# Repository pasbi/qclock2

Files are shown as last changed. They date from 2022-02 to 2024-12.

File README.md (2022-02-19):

# qclock2
Code, Schematics, Photos of the WortUhr Hack

The WORTUHR is a clock that displays the current time in form of glowing words.
This is about the German variant.

Note: The instance I got is presumably a cheap copy of a more expensive design https://qlocktwo.com/.

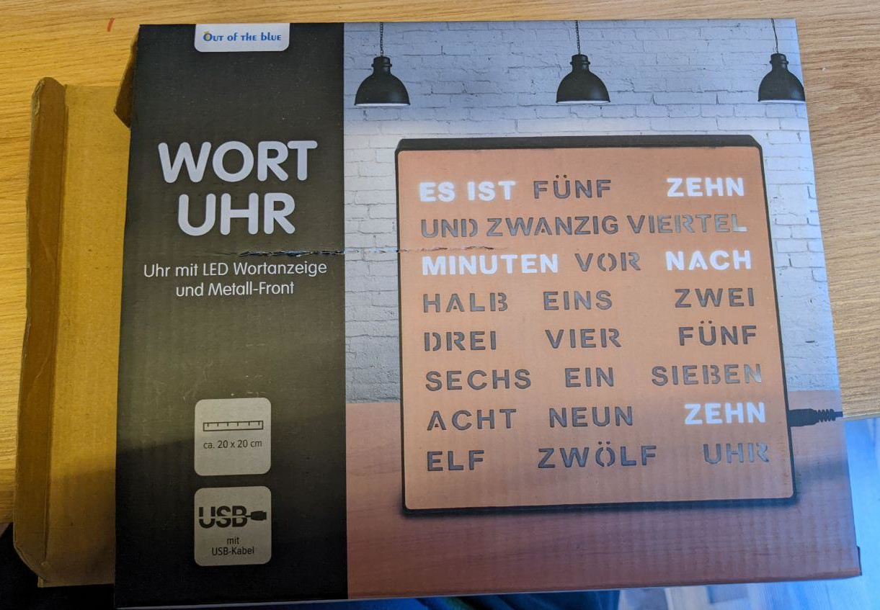
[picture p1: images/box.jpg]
Box


## Original Design

There is a metal cover of size 20cm x 20cm.
25 German words are blanked out.
It has a DC 5V 1A power connector and two buttons (`+`) and (`-`).
The plastic housing is 4 cm thick and encloses the metal sheet completey.
Inside there is a PCB whith 25 LED-groups, one group per word, with varying number of LEDs per group.
There's further two groups with each five LED drivers (transitor and multiple resistors), one IC, a quartz and few other passive components.
After powering the the PCB, the clock displays 12:00 ("ES IST ZWÖLF UHR").
The time can be adjusted using the two buttons.

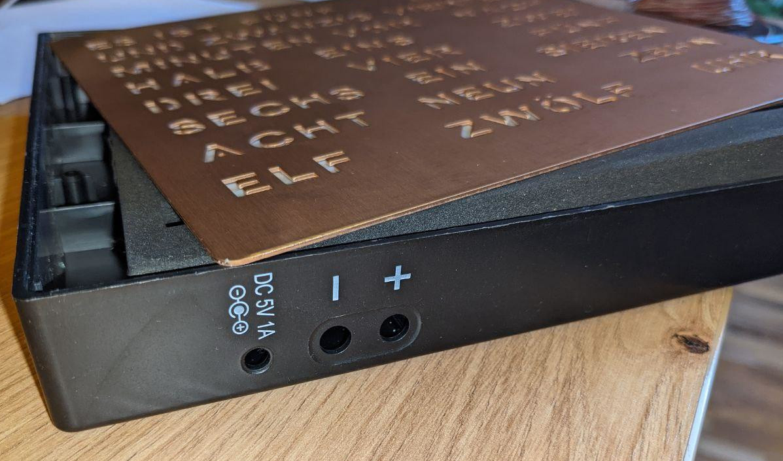
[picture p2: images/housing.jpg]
housing

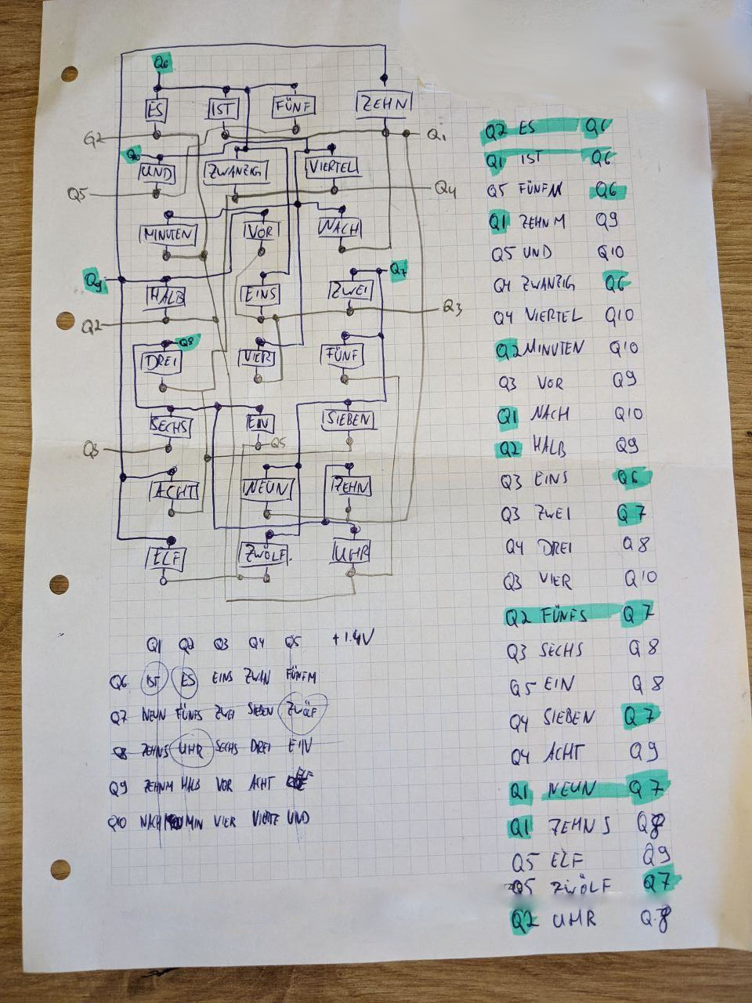
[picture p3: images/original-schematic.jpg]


## Problem

The problem with the original product is that it does reset every time power is disconnected.
That makes it inconvenient to use occasionally.

## Idea

Implement some circuit that synchronizes the time via NTP.

## Implementation

The original driver chip has been unsoldered, the 10 transistors on the board have been soldered to cables and dupont-connectors.

A 8266 and MCP23017 are connected via I²C.
The MCP keeps the time and synchronizes regularly via WIFI and NTP.
Since the watch works at 5V and the 8266 at 3.3V, a two-channel bidirectional logic level converter is required to translate the I²C signals.

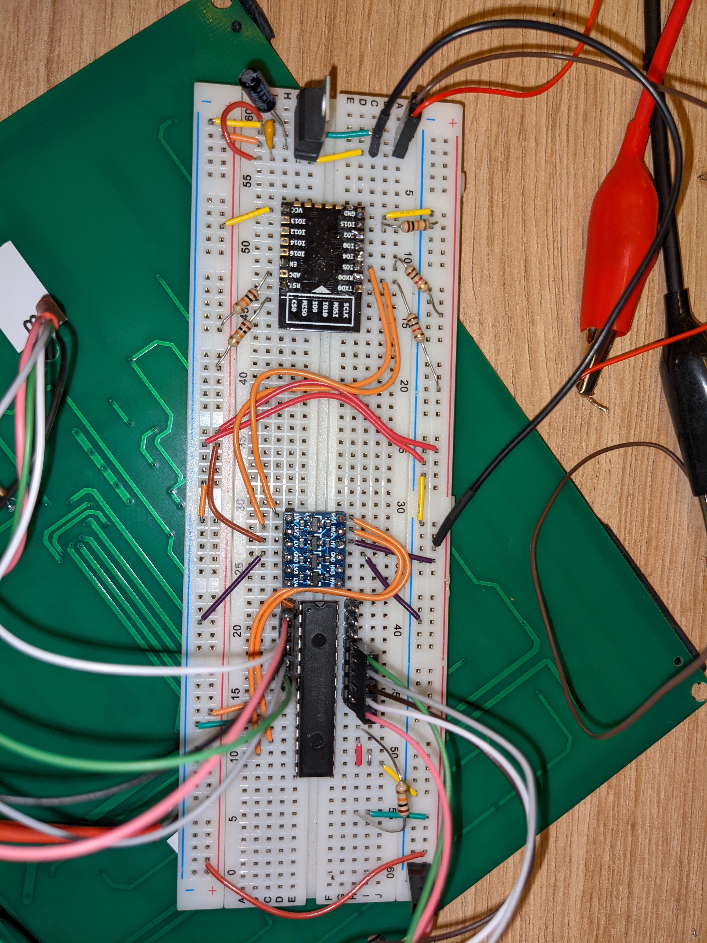
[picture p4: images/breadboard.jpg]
breadboard

breadboard-pcb
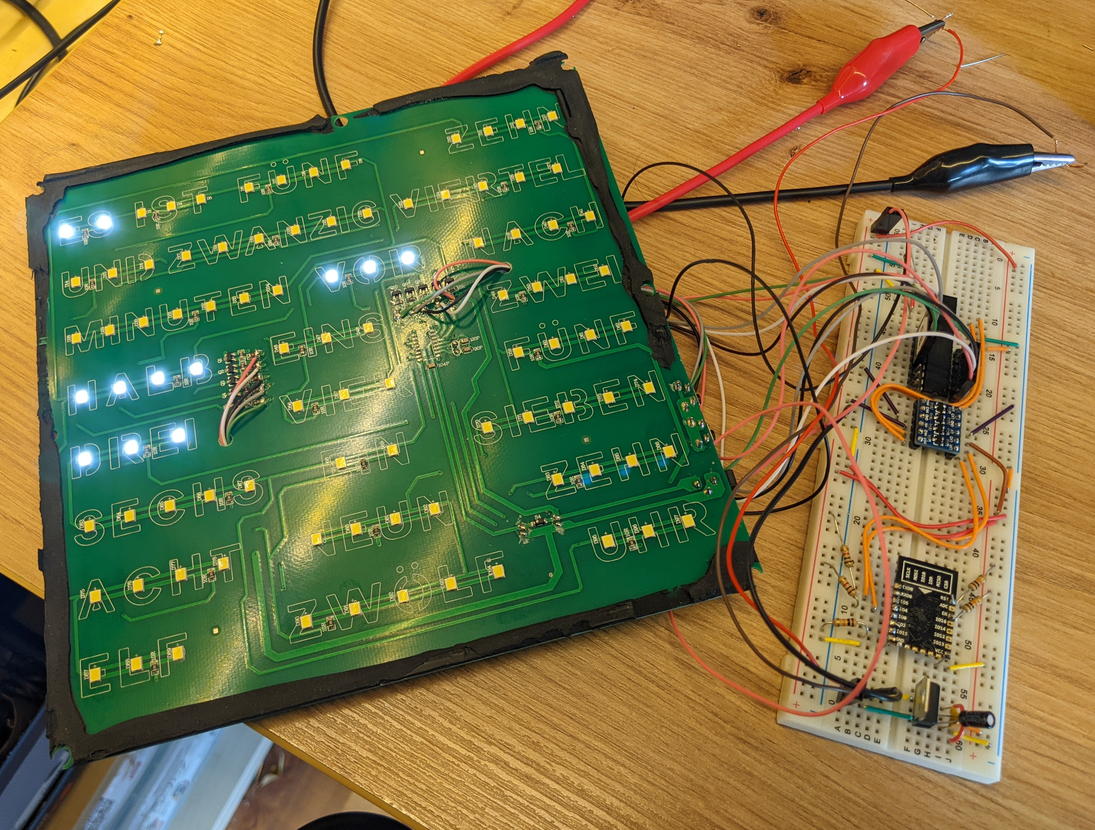
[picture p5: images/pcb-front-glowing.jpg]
pcb-front

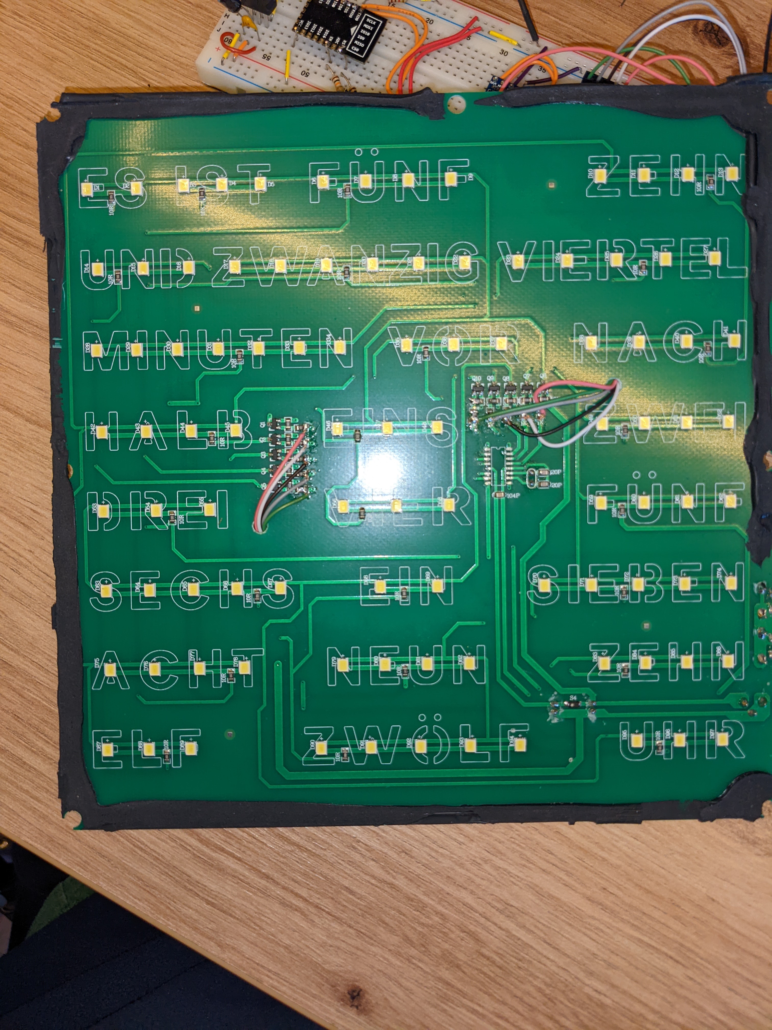
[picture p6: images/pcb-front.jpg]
pcb-front-glowing


Porting the breadboard to a sodered board turned out messy, error-prone and cumbersome.
Ordering a printed PCB seems to be the better choice.

kicad-files can be found in the repo:

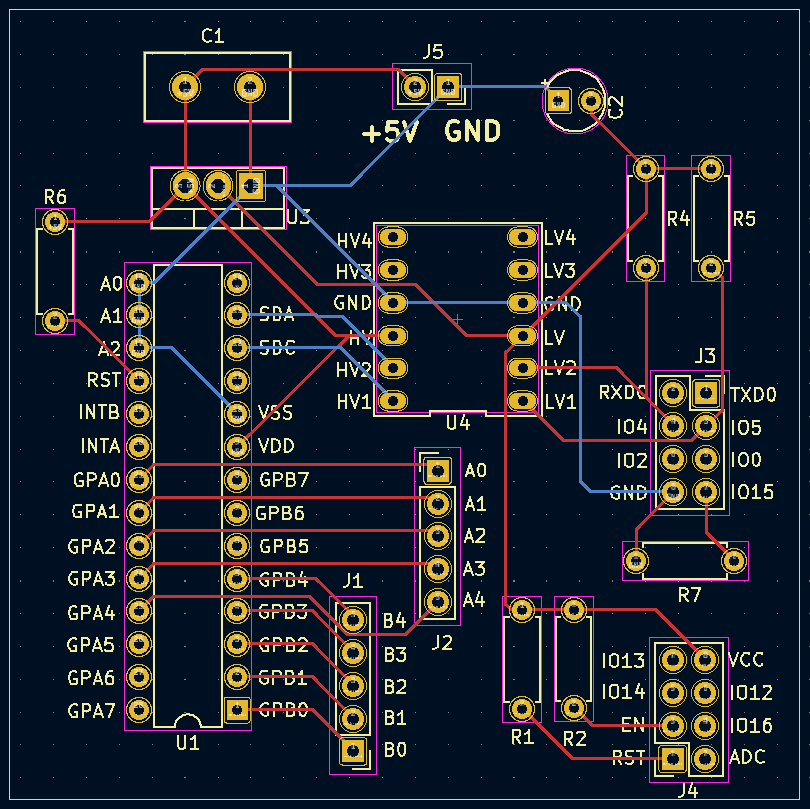
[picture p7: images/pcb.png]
custom pcb

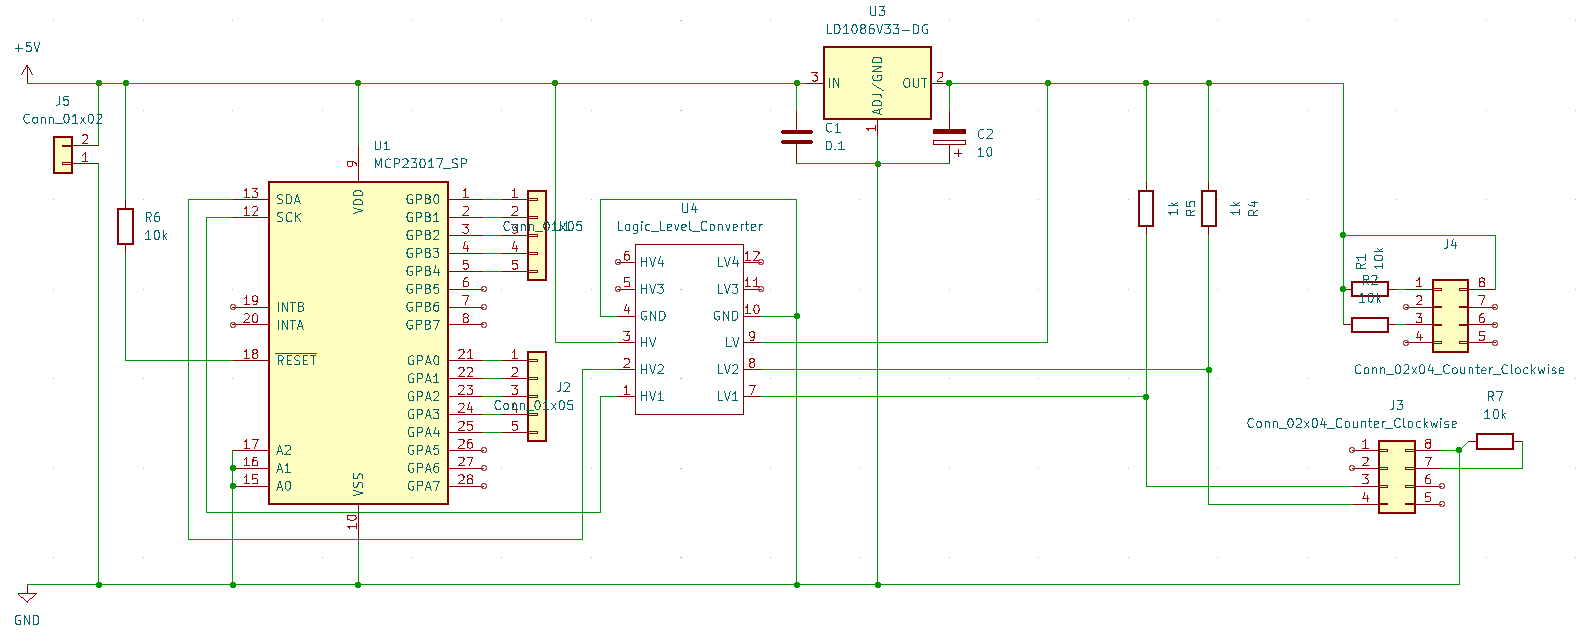
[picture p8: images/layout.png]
layout


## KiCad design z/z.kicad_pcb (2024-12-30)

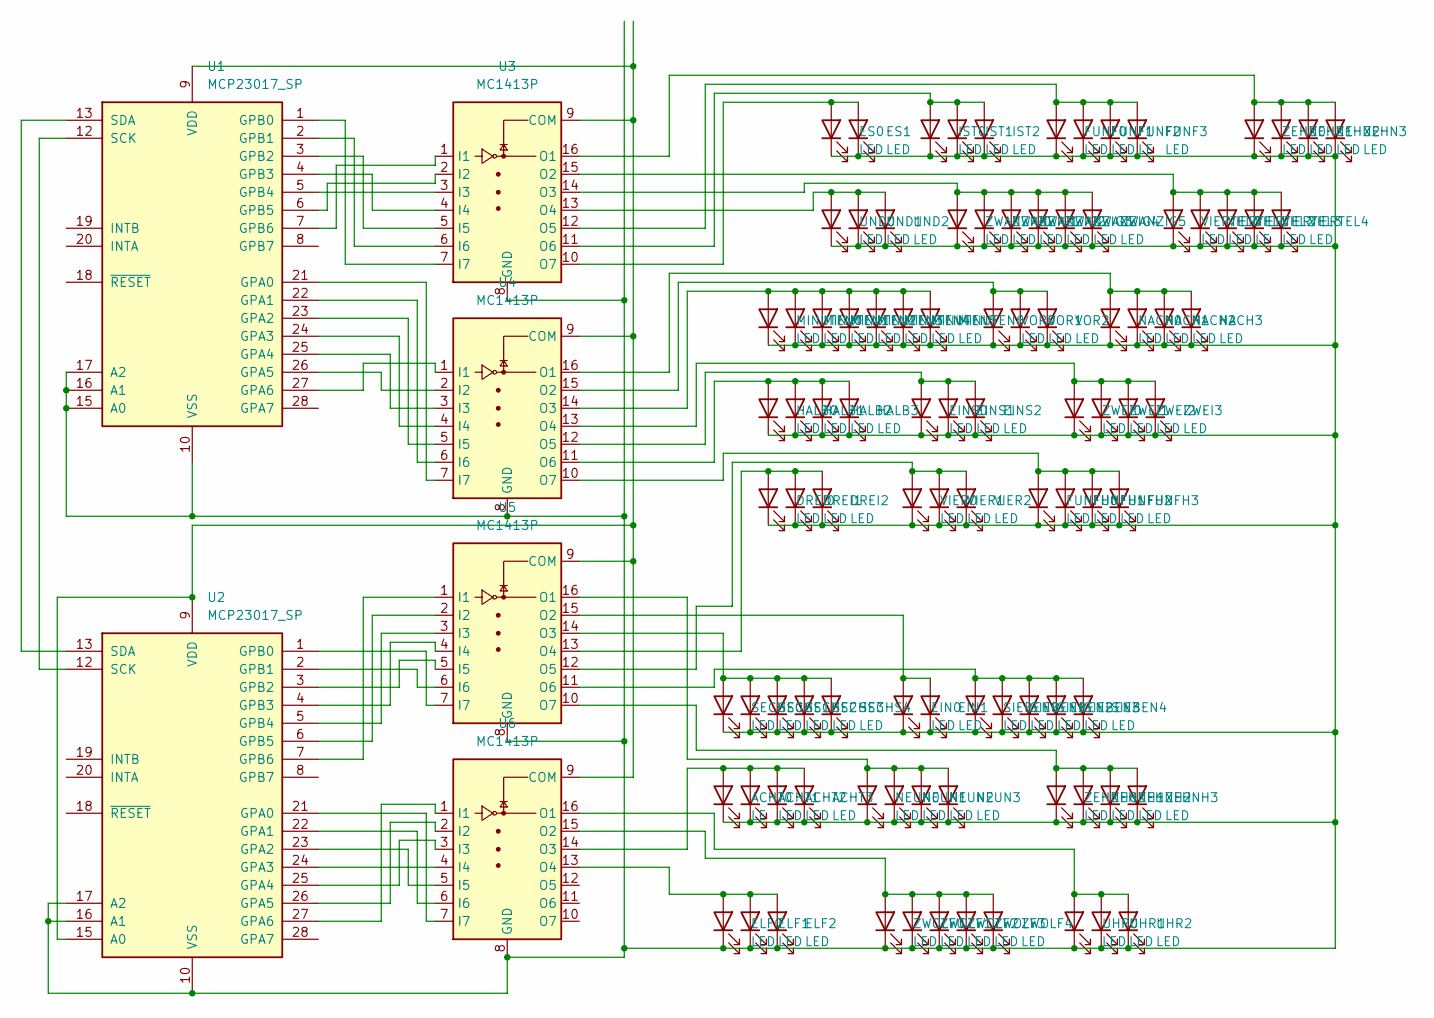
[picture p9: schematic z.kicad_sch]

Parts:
ACHT0: LE; LED_D5.0mm_Clear
ACHT1, ACHT2, ACHT3: LED; LED_D5.0mm_Clear
DREI0, DREI1, DREI2: LED; LED_D5.0mm_Clear
EIN0, EIN1: LED; LED_D5.0mm_Clear
EINS0, EINS1, EINS2: LED; LED_D5.0mm_Clear
ELF0, ELF1, ELF2: LED; LED_D5.0mm_Clear
ES0, ES1: LED; LED_D5.0mm_Clear
FUNF0, FUNF1, FUNF3: LED; LED_D5.0mm_Clear
FUNF2: LE; LED_D5.0mm_Clear
FUNFH0, FUNFH1, FUNFH2, FUNFH3: LED; LED_D5.0mm_Clear
HALB0, HALB1, HALB2, HALB3: LED; LED_D5.0mm_Clear
IST0, IST1, IST2: LED; LED_D5.0mm_Clear
MINUTEN0, MINUTEN1, MINUTEN2, MINUTEN3, MINUTEN4, MINUTEN5, MINUTEN6: LED; LED_D5.0mm_Clear
NACH0, NACH1, NACH2, NACH3: LED; LED_D5.0mm_Clear
NEUN0, NEUN1, NEUN2, NEUN3: LED; LED_D5.0mm_Clear
SECHS0, SECHS1, SECHS2, SECHS3, SECHS4: LED; LED_D5.0mm_Clear
SIEBEN0, SIEBEN1, SIEBEN2, SIEBEN3, SIEBEN4: LED; LED_D5.0mm_Clear
U1, U2: MCP23017_SP; DIP-28_W7.62mm
U3, U4, U5, U6: MC1413P; DIP-16_W7.62mm
UHR0, UHR1, UHR2: LED; LED_D5.0mm_Clear
UND0, UND1, UND2: LED; LED_D5.0mm_Clear
VIER0, VIER1, VIER2: LED; LED_D5.0mm_Clear
VIERTEL0, VIERTEL1, VIERTEL3, VIERTEL4: LED; LED_D5.0mm_Clear
VIERTEL2: LE; LED_D5.0mm_Clear
VOR0, VOR1, VOR2: LED; LED_D5.0mm_Clear
ZEHN0, ZEHN1, ZEHN2, ZEHN3: LED; LED_D5.0mm_Clear
ZEHNH0, ZEHNH1, ZEHNH2, ZEHNH3: LED; LED_D5.0mm_Clear
ZWANZIG0, ZWANZIG1, ZWANZIG2, ZWANZIG3, ZWANZIG4, ZWANZIG5: LED; LED_D5.0mm_Clear
ZWEI0, ZWEI1, ZWEI2, ZWEI3: LED; LED_D5.0mm_Clear
ZWOLF0, ZWOLF1, ZWOLF2, ZWOLF3, ZWOLF4: LED; LED_D5.0mm_Clear

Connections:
unnamed: ACHT0.2 (A), ACHT1.2 (A), ACHT2.2 (A), ACHT3.2 (A), U6.14 (O3)
unnamed: DREI0.2 (A), DREI1.2 (A), DREI2.2 (A), U5.13 (O4)
unnamed: EIN0.2 (A), EIN1.2 (A), U5.15 (O2)
unnamed: EINS0.2 (A), EINS1.2 (A), EINS2.2 (A), U4.12 (O5)
unnamed: ELF0.2 (A), ELF1.2 (A), ELF2.2 (A), U6.13 (O4)
unnamed: ES0.2 (A), ES1.2 (A), U3.10 (O7)
unnamed: FUNF0.2 (A), FUNF1.2 (A), FUNF2.2 (A), FUNF3.2 (A), U3.12 (O5)
unnamed: FUNFH0.2 (A), FUNFH1.2 (A), FUNFH2.2 (A), FUNFH3.2 (A), U4.10 (O7)
unnamed: HALB0.2 (A), HALB1.2 (A), HALB2.2 (A), HALB3.2 (A), U4.11 (O6)
unnamed: IST0.2 (A), IST1.2 (A), IST2.2 (A), U3.11 (O6)
unnamed: MINUTEN0.2 (A), MINUTEN1.2 (A), MINUTEN2.2 (A), MINUTEN3.2 (A), MINUTEN4.2 (A), MINUTEN5.2 (A), MINUTEN6.2 (A), U4.14 (O3)
unnamed: NACH0.2 (A), NACH1.2 (A), NACH2.2 (A), NACH3.2 (A), U4.16 (O1)
unnamed: NEUN0.2 (A), NEUN1.2 (A), NEUN2.2 (A), NEUN3.2 (A), U5.16 (O1)
unnamed: SECHS0.2 (A), SECHS1.2 (A), SECHS2.2 (A), SECHS3.2 (A), SECHS4.2 (A), U5.14 (O3)
unnamed: SIEBEN0.2 (A), SIEBEN1.2 (A), SIEBEN2.2 (A), SIEBEN3.2 (A), SIEBEN4.2 (A), U5.11 (O6)
unnamed: U1.3 (GPB2), U3.5 (I5)
unnamed: U1.4 (GPB3), U3.4 (I4)
unnamed: U1.6 (GPB5), U3.2 (I2)
unnamed: U1.9 (VDD), U2.9 (VDD), U2.15 (A0), U3.9 (COM), U4.9 (COM), U5.9 (COM), U6.9 (COM)
unnamed: U1.12 (SCK), U2.12 (SCK)
unnamed: U1.13 (SDA), U2.13 (SDA)
unnamed: U1.22 (GPA1), U4.6 (I6)
unnamed: U1.23 (GPA2), U4.5 (I5)
unnamed: U1.24 (GPA3), U4.4 (I4)
unnamed: U1.25 (GPA4), U4.3 (I3)
unnamed: U1.26 (GPA5), U4.2 (I2)
unnamed: U1.27 (GPA6), U4.1 (I1)
unnamed: U2.1 (GPB0), U5.7 (I7)
unnamed: U2.2 (GPB1), U5.6 (I6)
unnamed: U2.22 (GPA1), U6.6 (I6)
unnamed: U2.23 (GPA2), U6.5 (I5)
unnamed: U2.24 (GPA3), U6.4 (I4)
unnamed: U2.25 (GPA4), U6.3 (I3)
unnamed: U1.7 (GPB6), U3.1 (I1)
unnamed: U1.5 (GPB4), U3.3 (I3)
unnamed: U1.2 (GPB1), U3.6 (I6)
unnamed: U1.1 (GPB0), U3.7 (I7)
unnamed: U1.21 (GPA0), U4.7 (I7)
unnamed: U2.7 (GPB6), U5.1 (I1)
unnamed: U2.6 (GPB5), U5.2 (I2)
unnamed: U2.5 (GPB4), U5.3 (I3)
unnamed: U2.4 (GPB3), U5.4 (I4)
unnamed: U2.3 (GPB2), U5.5 (I5)
unnamed: U5.10 (O7), ZEHNH0.2 (A), ZEHNH1.2 (A), ZEHNH2.2 (A), ZEHNH3.2 (A)
unnamed: U2.27 (GPA6), U6.1 (I1)
unnamed: U2.26 (GPA5), U6.2 (I2)
unnamed: U2.21 (GPA0), U6.7 (I7)
unnamed: U6.16 (O1), UHR0.2 (A), UHR1.2 (A), UHR2.2 (A)
unnamed: U3.13 (O4), UND0.2 (A), UND1.2 (A), UND2.2 (A)
unnamed: U5.12 (O5), VIER0.2 (A), VIER1.2 (A), VIER2.2 (A)
unnamed: U3.15 (O2), VIERTEL0.2 (A), VIERTEL1.2 (A), VIERTEL2.2 (A), VIERTEL3.2 (A), VIERTEL4.2 (A)
unnamed: U4.15 (O2), VOR0.2 (A), VOR1.2 (A), VOR2.2 (A)
unnamed: ACHT0.1 (K), ACHT1.1 (K), ACHT2.1 (K), ACHT3.1 (K), DREI0.1 (K), DREI1.1 (K), DREI2.1 (K), EIN0.1 (K), EIN1.1 (K), EINS0.1 (K), EINS1.1 (K), EINS2.1 (K), ELF0.1 (K), ELF1.1 (K), ELF2.1 (K), ES0.1 (K), ES1.1 (K), FUNF0.1 (K), FUNF1.1 (K), FUNF2.1 (K), FUNF3.1 (K), FUNFH0.1 (K), FUNFH1.1 (K), FUNFH2.1 (K), FUNFH3.1 (K), HALB0.1 (K), HALB1.1 (K), HALB2.1 (K), HALB3.1 (K), IST0.1 (K), IST1.1 (K), IST2.1 (K), MINUTEN0.1 (K), MINUTEN1.1 (K), MINUTEN2.1 (K), MINUTEN3.1 (K), MINUTEN4.1 (K), MINUTEN5.1 (K), MINUTEN6.1 (K), NACH0.1 (K), NACH1.1 (K), NACH2.1 (K), NACH3.1 (K), NEUN0.1 (K), NEUN1.1 (K), NEUN2.1 (K), NEUN3.1 (K), SECHS0.1 (K), SECHS1.1 (K), SECHS2.1 (K), SECHS3.1 (K), SECHS4.1 (K), SIEBEN0.1 (K), SIEBEN1.1 (K), SIEBEN2.1 (K), SIEBEN3.1 (K), SIEBEN4.1 (K), U1.10 (VSS), U1.15 (A0), U1.16 (A1), U1.17 (A2), U2.10 (VSS), U2.16 (A1), U2.17 (A2), U3.8 (GND), U4.8 (GND), U5.8 (GND), U6.8 (GND), UHR0.1 (K), UHR1.1 (K), UHR2.1 (K), UND0.1 (K), UND1.1 (K), UND2.1 (K), VIER0.1 (K), VIER1.1 (K), VIER2.1 (K), VIERTEL0.1 (K), VIERTEL1.1 (K), VIERTEL2.1 (K), VIERTEL3.1 (K), VIERTEL4.1 (K), VOR0.1 (K), VOR1.1 (K), VOR2.1 (K), ZEHN0.1 (K), ZEHN1.1 (K), ZEHN2.1 (K), ZEHN3.1 (K), ZEHNH0.1 (K), ZEHNH1.1 (K), ZEHNH2.1 (K), ZEHNH3.1 (K), ZWANZIG0.1 (K), ZWANZIG1.1 (K), ZWANZIG2.1 (K), ZWANZIG3.1 (K), ZWANZIG4.1 (K), ZWANZIG5.1 (K), ZWEI0.1 (K), ZWEI1.1 (K), ZWEI2.1 (K), ZWEI3.1 (K), ZWOLF0.1 (K), ZWOLF1.1 (K), ZWOLF2.1 (K), ZWOLF3.1 (K), ZWOLF4.1 (K)
unnamed: U3.16 (O1), ZEHN0.2 (A), ZEHN1.2 (A), ZEHN2.2 (A), ZEHN3.2 (A)
unnamed: U3.14 (O3), ZWANZIG0.2 (A), ZWANZIG1.2 (A), ZWANZIG2.2 (A), ZWANZIG3.2 (A), ZWANZIG4.2 (A), ZWANZIG5.2 (A)
unnamed: U4.13 (O4), ZWEI0.2 (A), ZWEI1.2 (A), ZWEI2.2 (A), ZWEI3.2 (A)
unnamed: U6.15 (O2), ZWOLF0.2 (A), ZWOLF1.2 (A), ZWOLF2.2 (A), ZWOLF3.2 (A), ZWOLF4.2 (A)

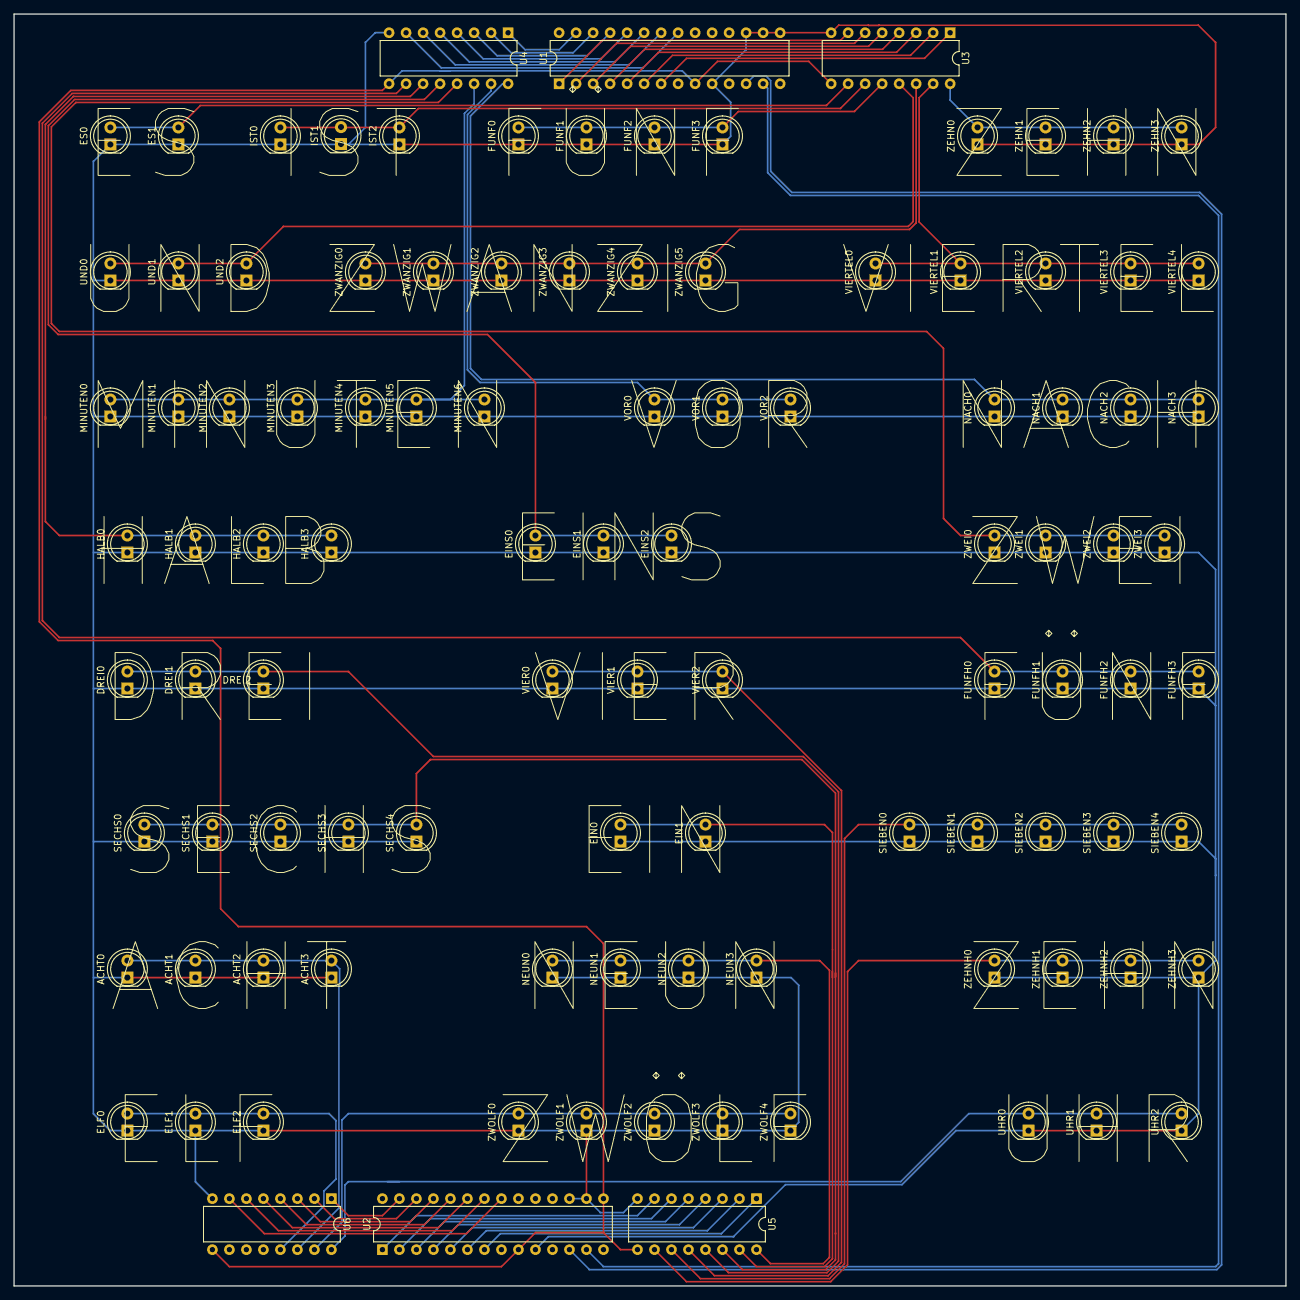
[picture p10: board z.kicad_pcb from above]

Board: 2 copper layers, 190.0 x 190.0 mm, 103 parts (0 on the bottom side), 57 nets.

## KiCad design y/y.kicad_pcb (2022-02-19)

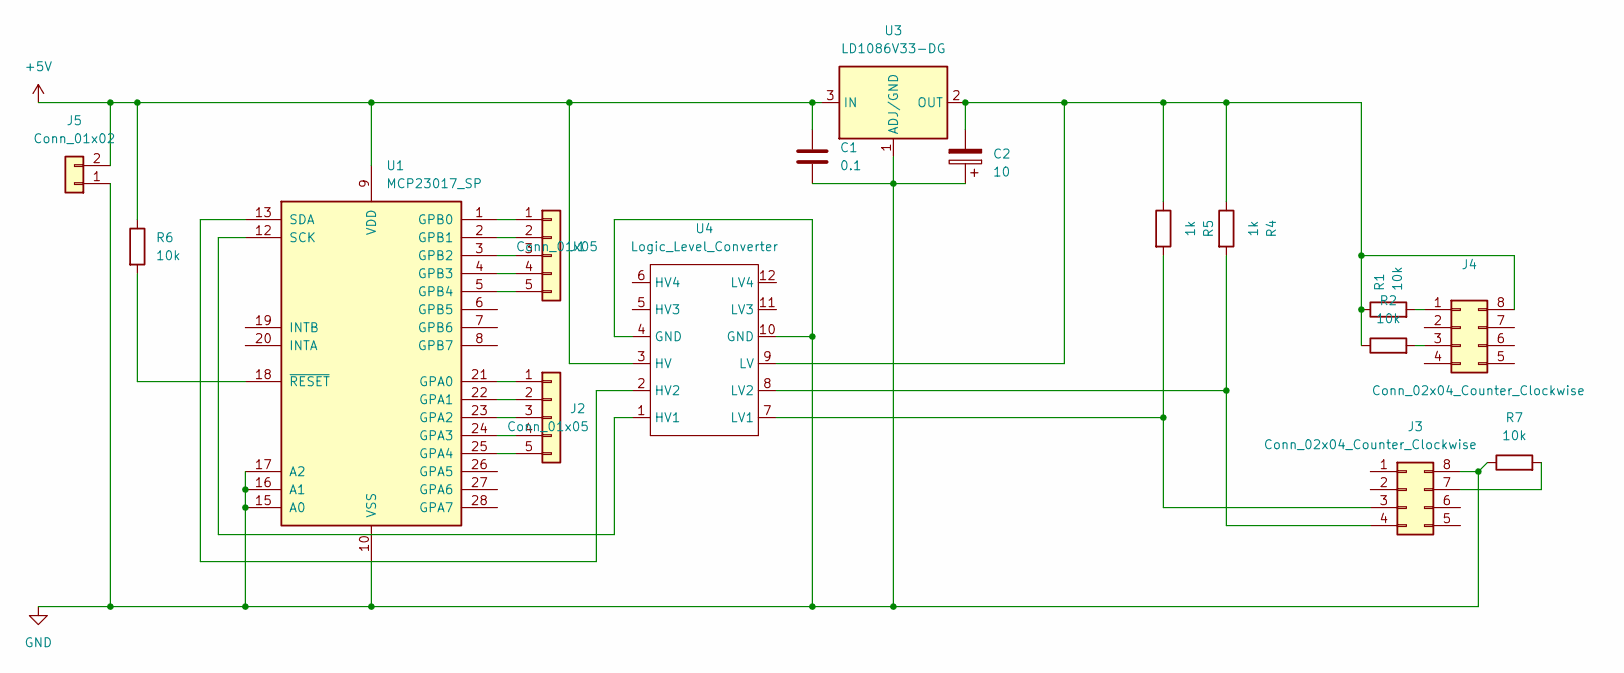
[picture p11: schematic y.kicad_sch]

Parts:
C1: 0.1; C_Disc_D11.0mm_W5.0mm_P5.00mm
C2: 10; CP_Radial_Tantal_D4.5mm_P2.50mm
J1, J2: Conn_01x05; PinHeader_1x05_P2.54mm_Vertical
J3, J4: Conn_02x04_Counter_Clockwise; PinSocket_2x04_P2.54mm_Vertical
J5: Conn_01x02; PinSocket_1x02_P2.54mm_Vertical
R1, R2, R6, R7: 10k; R_Axial_DIN0207_L6.3mm_D2.5mm_P7.62mm_Horizontal
R4, R5: 1k; R_Axial_DIN0207_L6.3mm_D2.5mm_P7.62mm_Horizontal
U1: MCP23017_SP; DIP-28_W7.62mm
U3: LD1086V33-DG; TO-220-3_Vertical
U4: Logic_Level_Converter; Logic Level Converter

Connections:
+5V: C1.1, J5.2, R6.1, U1.9 (VDD), U3.3 (IN), U4.3 (HV)
GND: C1.2, C2.1, J3.8 (GND), J5.1, R7.1, U1.10 (VSS), U1.15 (A0), U1.16 (A1), U1.17 (A2), U3.1 (ADJ/GND), U4.4 (GND), U4.10 (GND)
unnamed: C2.2, J4.8 (VCC), R1.1, R2.1, R4.1, R5.1, U3.2 (OUT), U4.9 (LV)
unnamed: J1.1, U1.1 (GPB0)
unnamed: J1.2, U1.2 (GPB1)
unnamed: J1.3, U1.3 (GPB2)
unnamed: J1.4, U1.4 (GPB3)
unnamed: J1.5, U1.5 (GPB4)
unnamed: J2.1, U1.21 (GPA0)
unnamed: J2.2, U1.22 (GPA1)
unnamed: J2.3, U1.23 (GPA2)
unnamed: J2.4, U1.24 (GPA3)
unnamed: J2.5, U1.25 (GPA4)
unnamed: J3.4 (IO4), R4.2, U4.8 (LV2)
unnamed: J4.1 (RST), R1.2
unnamed: J4.3 (EN), R2.2
unnamed: J3.3 (IO5), R5.2, U4.7 (LV1)
unnamed: R6.2, U1.18 (~RESET)
unnamed: J3.7 (IO15), R7.2
unnamed: U1.12 (SCK), U4.1 (HV1)
unnamed: U1.13 (SDA), U4.2 (HV2)

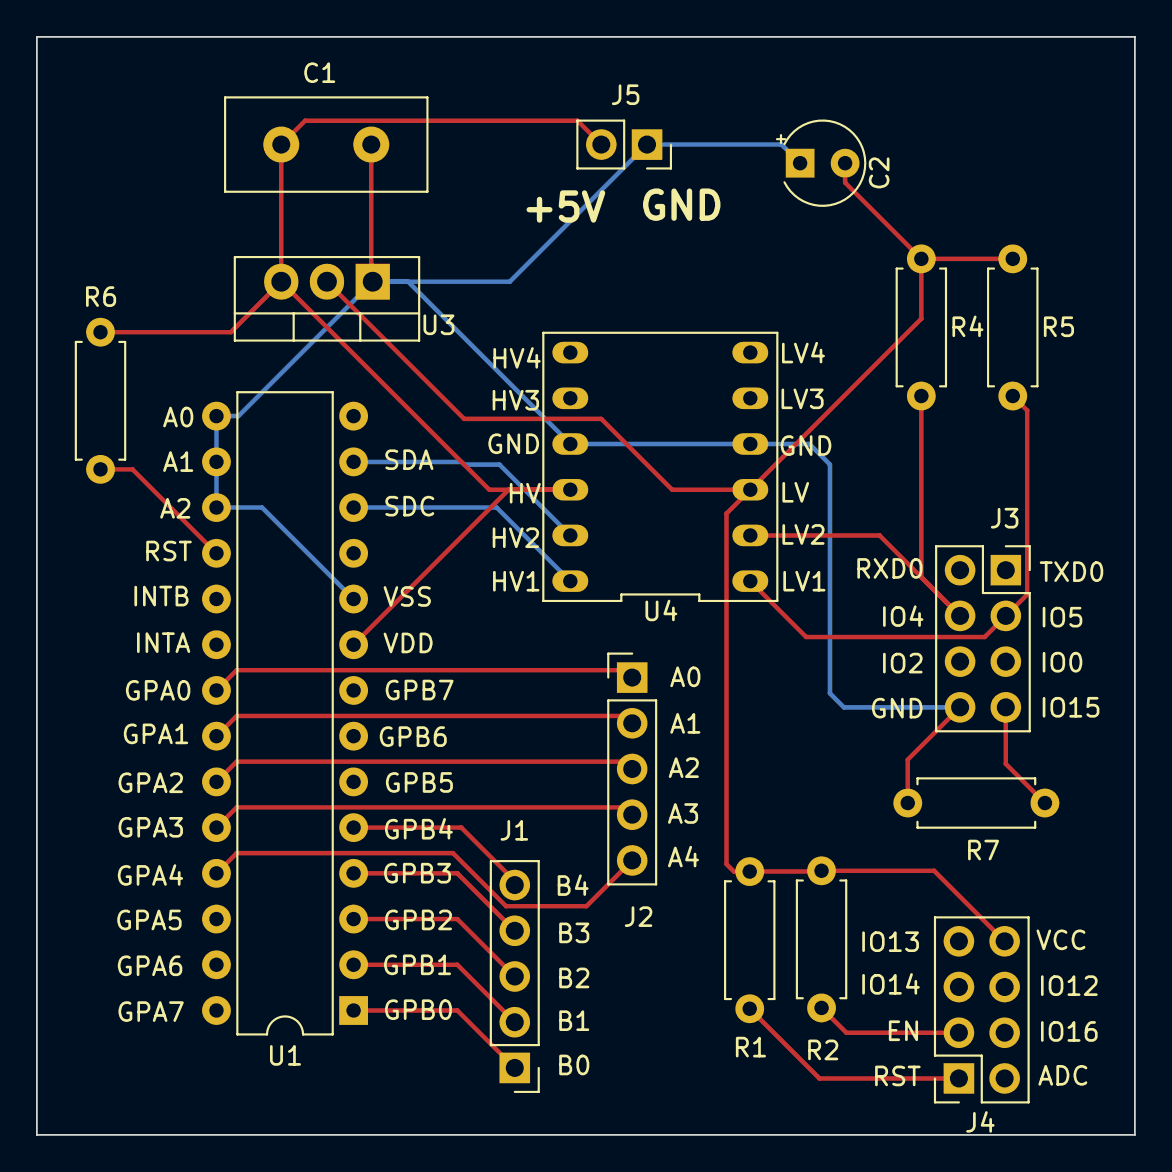
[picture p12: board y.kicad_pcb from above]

Board: 2 copper layers, 61.0 x 61.0 mm, 16 parts (0 on the bottom side), 21 nets.

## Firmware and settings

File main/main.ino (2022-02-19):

#include <Adafruit_MCP23X17.h>
#include <Wire.h>
#include <NTPClient.h>
#include <ESP8266WiFi.h>
#include <WiFiUdp.h>
#include <array>
#include "secrets.h"

Adafruit_MCP23X17 mcp;
static constexpr uint8_t mcp_address = 0;

void write_leds(const int id, const int value)
{
  const int ia = id % 5;
  const int ib = id / 5 + 8;
  mcp.digitalWrite(ia, value);
  mcp.digitalWrite(ib, value == HIGH ? LOW : HIGH);
}

/**
 * qa, qb represent the labels on the PCB, i.e., Q1 and Q7
 */
static constexpr int compute_id(const int qa, const int qb)
{
  return (qa - 1) + (qb - 6) * 5;
}

static constexpr std::array<int, 25> cs {
  compute_id(2, 6),  // connects to Q2, Q6
  compute_id(1, 6),  // connects to Q1, Q6
  compute_id(5, 6),  // connects to Q5, Q6
  compute_id(1, 9),  // connects to Q1, Q9
  compute_id(5, 10), // etc.
  compute_id(4, 6),
  compute_id(4, 10),
  compute_id(2, 10),
  compute_id(3, 9),
  compute_id(1, 10),
  compute_id(2, 9),
  compute_id(3, 6),
  compute_id(3, 7),
  compute_id(4, 8),
  compute_id(3, 10),
  compute_id(2, 7),
  compute_id(3, 8),
  compute_id(5, 8),
  compute_id(4, 7),
  compute_id(4, 9),
  compute_id(1, 7),
  compute_id(1, 8),
  compute_id(5, 9),
  compute_id(5, 7),
  compute_id(2, 8),
};

static constexpr auto ES = cs[0];
static constexpr auto IST = cs[1];
static constexpr auto FUNF = cs[2];
static constexpr auto ZEHN = cs[3];
static constexpr auto UND = cs[4];
static constexpr auto ZWANZIG = cs[5];
static constexpr auto VIERTEL = cs[6];
static constexpr auto MINUTEN = cs[7];
static constexpr auto VOR = cs[8];
static constexpr auto NACH = cs[9];
static constexpr auto HALB = cs[10];
static constexpr auto EINS = cs[11];
static constexpr auto ZWEI = cs[12];
static constexpr auto DREI = cs[13];
static constexpr auto VIER = cs[14];
static constexpr auto FUNF_H = cs[15];
static constexpr auto SECHS = cs[16];
static constexpr auto EIN = cs[17];
static constexpr auto SIEBEN = cs[18];
static constexpr auto ACHT = cs[19];
static constexpr auto NEUN = cs[20];
static constexpr auto ZEHN_H = cs[21];
static constexpr auto ELF = cs[22];
static constexpr auto ZWOLF = cs[23];
static constexpr auto UHR = cs[24];
static constexpr auto NONE = -1;

#define picture_size 6        // the number of LEDs that appear to be ON at the same time
#define Picture std::array<int, picture_size>

void set_picture(const Picture& picture)
{
  static constexpr auto write_leds_duration_us = 0;  // approximation to make all picture equally bright
  static constexpr auto additional_duty_us = 0;
  for (std::size_t i = 0; i < picture.size(); ++i) {
    const auto p = picture[i];
    if (p > 0) {
      write_leds(p, HIGH);
//      delayMicroseconds(additional_duty_us);
      write_leds(p, LOW);
    } else {
//      delayMicroseconds(write_leds_duration_us + additional_duty_us);
    }
  }
}

static constexpr std::array<int, 12> c2     {NONE,  FUNF,    ZEHN,    VIERTEL, ZWANZIG, FUNF, NONE, FUNF, ZEHN, VIERTEL, ZEHN,    FUNF};
static constexpr std::array<int, 12> c3     {NONE,  MINUTEN, MINUTEN, NONE,    MINUTEN, VOR,  NONE, NACH, NACH, NONE,    MINUTEN, MINUTEN};
static constexpr std::array<int, 12> c4     {NONE,  NACH,    NACH,    NACH,    NACH,    HALB, HALB, HALB, HALB, VOR,     VOR,     VOR};
static constexpr std::array<int, 12> offset {0,     0,       0,       0,       0,       1,    1,    1,    1,    1,       1,       1};
static constexpr std::array<int, 12> hours  {ZWOLF, EINS,    ZWEI, DREI, VIER, FUNF_H, SECHS, SIEBEN, ACHT, NEUN, ZEHN_H, ELF};

int python_like_mod(const int dividend, const int divisor)
{
  return (dividend % divisor + divisor) % divisor;
}

int get_hour(const int hour, const int minute5)
{
  if (minute5 == 0 && hour == 1) {
    return EIN;
  } else {
    return hours[(hour + offset[minute5]) % 12];
  }
}

Picture picture_from_clock(const int hour, const int minute)
{
  const auto minute5 = python_like_mod(minute, 60) / 5;
  if (minute5 == 0) {
    return {ES, IST, get_hour(hour, minute5), UHR, NONE, NONE};
  } else {
    return {ES, IST, c2[minute5], c3[minute5], c4[minute5], get_hour(hour, minute5)};
  }
}

void test_leds_single()
{
  for (int i = 0; i < 25; ++i) {
    write_leds(cs[i], HIGH);
    delay(20);
    write_leds(cs[i], LOW);
  }
}

WiFiUDP ntpUDP;
const long utcOffsetInSeconds = 3600;
NTPClient timeClient(ntpUDP, "pool.ntp.org", utcOffsetInSeconds);

void setup()
{
  Serial.begin(74880);

  // setup connection to the port multiplier
  mcp.begin_I2C();
  for (int i = 0; i < 16; ++i) {
    mcp.pinMode(i, OUTPUT);
  }

  // initialize all leds
  for (int i = 0; i < 25; ++i) {
    write_leds(i, LOW);
  }

  // test all leds in sequence
  for (int i = 0; i < 2; ++i) {
    test_leds_single();
  }

  // connect to WIFI
  WiFi.begin(ssid, password);
  while (WiFi.status() != WL_CONNECTED) {
    Serial.print(".");
    for (int i = 0; i < 5; ++i) {
      write_leds(ES, HIGH);
      delay(50);
      write_leds(ES, LOW);
      delay(50);
    }
  }
  // init ntp client
  timeClient.begin();
  Serial.println("Setup successful");

  // blink 5 times slowly to indicate successful setup
  for (int i = 0; i < 5; ++i) {
    write_leds(ES, HIGH);
    delay(100);
    write_leds(ES, LOW);
    delay(100);
  }
}

const unsigned long ntp_update_interval_ms = 20 * 1000;

class Time
{
public:
  explicit Time(const NTPClient& tc)
    : m_ms_since_start_of_day(1000 * (60 * (60 * tc.getHours() + tc.getMinutes()) + tc.getSeconds()))
  {
  }

  void add_millis(int ms)
  {
    m_ms_since_start_of_day += ms;
  }

  int hours() const
  {
    return (m_ms_since_start_of_day / (1000 * 60 * 60)) % 12;
  }

  int minutes() const
  {
    return (m_ms_since_start_of_day / (1000 * 60)) % 60;
  }

  int seconds() const
  {
    return (m_ms_since_start_of_day / 1000) % 60;
  }

  void print(const char* msg) const
  {
    Serial.printf("Time (%s): %02i:%02i:%02i\n", msg, hours(), minutes(), seconds());
  }

private:
  int m_ms_since_start_of_day;
};

void loop()
{
  auto currentMillis = millis();
  const auto last_ntp_update = currentMillis;
  if (currentMillis + (2 * last_ntp_update) < currentMillis) {
    // peril of overflow, happens after ~49 days
    ESP.reset();
  }

  Serial.println("update ntp time");
  timeClient.update();
  const Time time_at_last_ntp_update(timeClient);

  while (currentMillis - last_ntp_update < ntp_update_interval_ms) {
    time_at_last_ntp_update.print("ntp");
    Time current_time = time_at_last_ntp_update;
    current_time.add_millis(currentMillis - last_ntp_update);
    Serial.printf("millis since last update: %ul\n", currentMillis - last_ntp_update);
    const auto picture = picture_from_clock(current_time.hours(), current_time.minutes());
    current_time.print("current");
    static constexpr auto n = 100; // bigger means less flicker, but watchdog will reset if too large.
    for (int k = 0; k < n; ++k) {
      set_picture(picture);
    }
    yield();
    currentMillis = millis();
  }
}

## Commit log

2022-02-19 add pcb files
    [y.kicad_pcb, y.kicad_sch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]
2024-12-30 add alternative layout z
    [z.kicad_pcb, z.kicad_sch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]
